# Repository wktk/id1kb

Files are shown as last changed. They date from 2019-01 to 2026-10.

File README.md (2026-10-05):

# id1kb

## parts per 1 PCB

| Name | Value | Comment |
|----|----|----|
| Pro Micro | 1 | |
| SK6812MINI | 8 | Optional |
| Key Switch | 8 | |
| MJ-4PP-9 | 1 | Required only if connect two kbds |
| Diode 1N4148 | 8 | 100V 200mA, Also supports SMD |

## case

3D printable bottom case.

| File | Comment |
|----|----|
| case/id1kb_case.stl | Full floor |
| case/id1kb_case_truss.stl | Truss floor, less material |
| case/id1kb_case.scad | OpenSCAD source, adjust pin size etc. in Customizer |

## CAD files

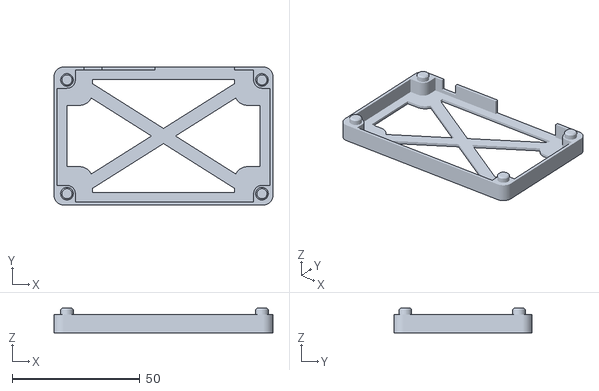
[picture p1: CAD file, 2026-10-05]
case/id1kb_case_truss.stl
85.6 x 54.0 x 9.60

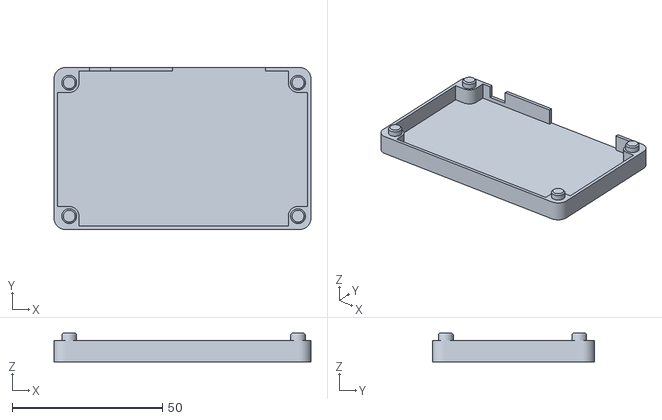
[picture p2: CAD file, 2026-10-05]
case/id1kb_case.stl
85.6 x 54.0 x 9.60

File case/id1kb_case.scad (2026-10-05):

// id1kb bottom tray case
// The tray shares the PCB's outline: its walls run under the PCB edge and the
// PCB rests on them, held by friction on the pins.
// Coordinates follow the top view (switch side up, "Designed by" text on the right),
// which matches KiCad's front view: origin at the PCB's top-left corner
// (USB/TRRS edge), y' grows downward.

/* [View] */
show_pcb = false;

/* [Board fit] */
// Clearance under the PCB for the Pro Micro, TRRS jack and reset switch.
under = 6.0;
pin_d = 4.95;
// How far the pin tip rises above the PCB's top surface.
pin_extra = 0.8;

/* [Openings] */
// The Pro Micro overhangs the top edge by ~2 mm, so the whole module needs room.
promicro_w = 20;
trrs_w = 9;
reset_w = 7;
reset_depth = 4.5;

/* [Case] */
floor_style = "full"; // [full, truss]
floor_t = 1.2;
wall = 1.2;
post_d = 6.5;

/* [Truss floor] */
truss_w = 5;
// Square pad inside each frame corner, room for a rubber foot.
foot_pad = 10;
// Radius of the pad's corner that faces the middle.
foot_r = 5;

/* [Hidden] */
$fn = 64;

pcb_w = 85.6;
pcb_h = 53.98;
pcb_r = 3.81;
pcb_t = 1.6;

holes = [[5.08, 5.08], [81.28, 5.08], [5.08, 49.53], [81.28, 49.53]];
promicro_x = 49.53;
trrs_x = 66.0;
reset_x = 15.28;
switches = [for (x = [11.43, 30.48, 49.53, 68.58], y = [21.59, 40.64]) [x, y]];

function pos(p) = [p[0], pcb_h - p[1]];

z_pcb = floor_t + under;

module outline(off) {
    translate([pcb_r, pcb_r])
        offset(r = pcb_r + off) square([pcb_w - 2 * pcb_r, pcb_h - 2 * pcb_r]);
}

// Measured from the PCB's corner, so it also covers the frame under the pad.
module foot_pad() {
    t = truss_w + foot_pad;
    square([t, t - foot_r]);
    square([t - foot_r, t]);
    translate([t - foot_r, t - foot_r]) circle(r = foot_r);
}

module floor_2d() {
    if (floor_style == "full") outline(0);
    else intersection() {
        outline(0);
        union() {
            difference() { outline(0); outline(-truss_w); }
            for (d = [[[0, 0], [pcb_w, pcb_h]], [[0, pcb_h], [pcb_w, 0]]])
                hull() for (p = d) translate(p) circle(d = truss_w);
            for (mx = [0, 1], my = [0, 1])
                translate([mx * pcb_w, my * pcb_h]) mirror([mx, 0]) mirror([0, my]) foot_pad();
        }
    }
}

module shell() {
    difference() {
        linear_extrude(z_pcb) outline(0);
        translate([0, 0, -1]) linear_extrude(z_pcb + 2) outline(-wall);
    }
    linear_extrude(floor_t) floor_2d();
}

// Starts slightly below its base so it fuses with the post instead of just touching it.
module pin(d) {
    hull() {
        translate([0, 0, -0.1]) cylinder(d = d, h = pcb_t + pin_extra - 0.4);
        cylinder(d = d - 1, h = pcb_t + pin_extra);
    }
}

// Bridged to the two nearest walls so no thin gap is left beside them.
module post_2d(h) {
    c = [h[0] < pcb_w / 2 ? 0 : pcb_w, h[1] < pcb_h / 2 ? 0 : pcb_h];
    intersection() {
        outline(0);
        for (e = [[c[0], h[1]], [h[0], c[1]]])
            hull() for (p = [h, e]) translate(pos(p)) circle(d = post_d);
    }
}

module posts() {
    for (h = holes) {
        linear_extrude(z_pcb) post_2d(h);
        translate(pos(h)) translate([0, 0, z_pcb]) pin(pin_d);
    }
}

module notch(x, w, z0) {
    translate([x - w / 2, pcb_h - wall - 1, z0]) cube([w, wall + 2, z_pcb]);
}

module case() {
    difference() {
        shell();
        // One opening for both: separate notches would leave a fragile ~2 mm strip between them.
        let (l = promicro_x - promicro_w / 2, r = trrs_x + trrs_w / 2)
            notch((l + r) / 2, r - l, floor_t);
        notch(reset_x, reset_w, z_pcb - reset_depth);
    }
    posts();
}

module pcb_ghost() {
    translate([0, 0, z_pcb]) difference() {
        linear_extrude(pcb_t) outline(0);
        for (h = holes) translate(pos(h)) translate([0, 0, -1]) cylinder(d = 4.8, h = pcb_t + 2);
    }
    for (s = switches) translate(pos(s)) translate([-7, -7, z_pcb + pcb_t]) cube([14, 14, 11]);
    translate([promicro_x - 9, pcb_h - 33 + 2, z_pcb - 5]) cube([18, 33, 5]);
    translate([trrs_x - 3, pcb_h - 12, z_pcb - 5]) cube([6, 12, 5]);
    translate([reset_x - 3.75, pcb_h - 8.7, z_pcb - 3.5]) cube([7.5, 7.5, 3.5]);
}

case();
if (show_pcb) %pcb_ghost();

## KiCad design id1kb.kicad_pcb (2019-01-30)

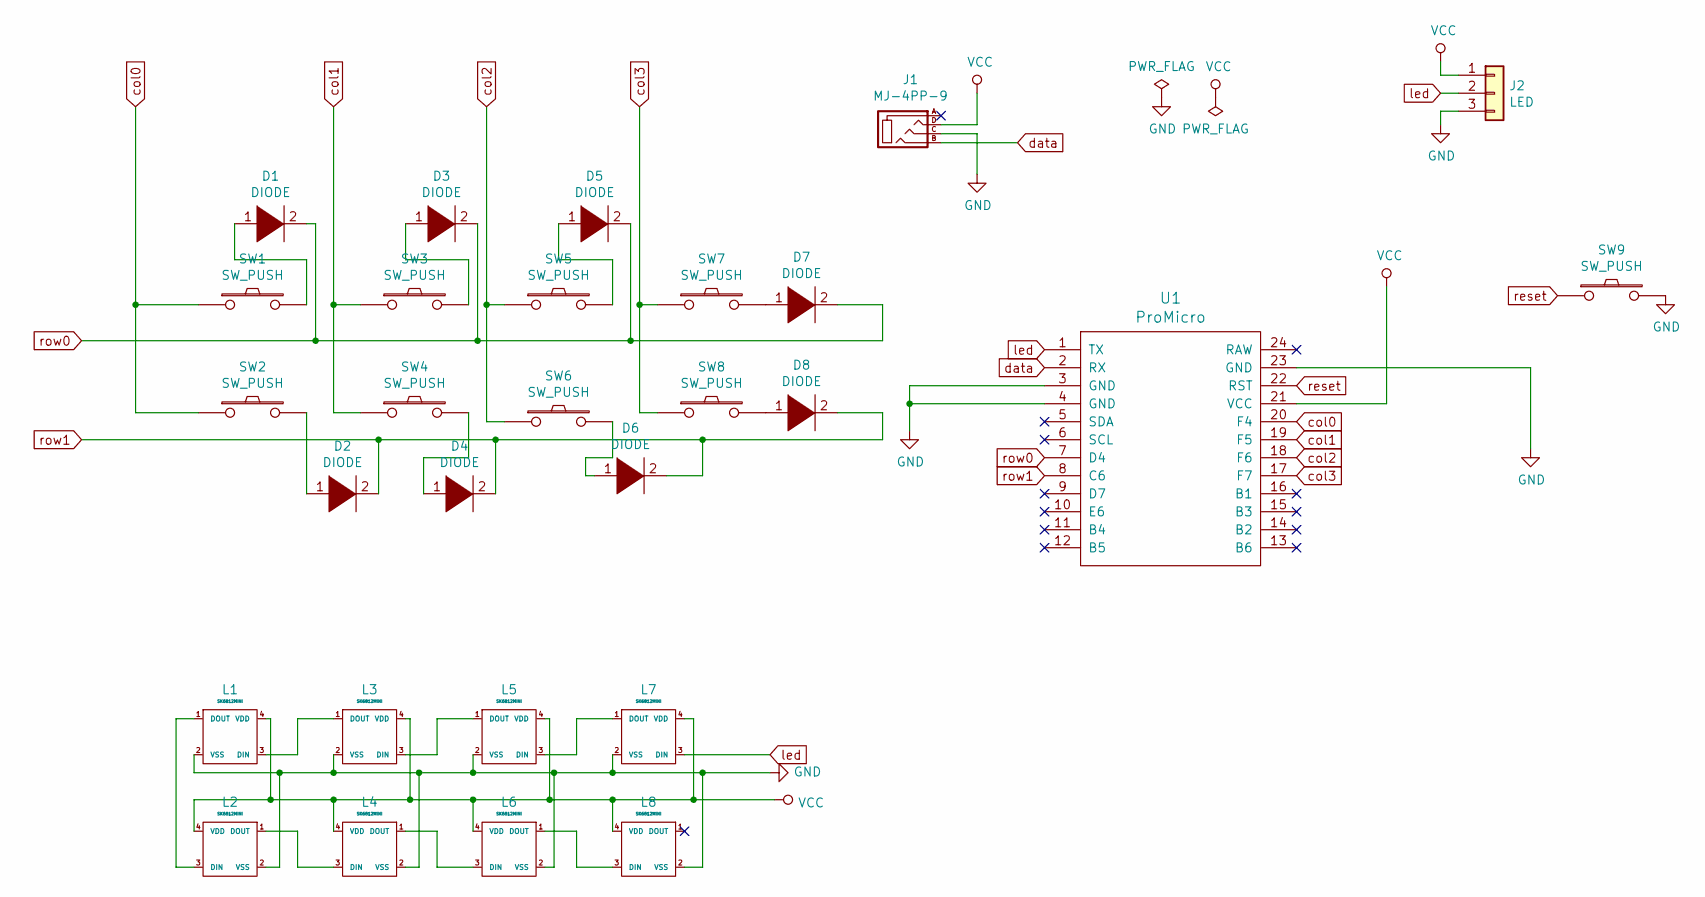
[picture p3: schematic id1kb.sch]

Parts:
D1, D2, D3, D4, D5, D6, D7, D8: DIODE; D3_TH_SMD
J1: MJ-4PP-9
J2: LED; StripLED_rev
L1, L2, L3, L4, L5, L6, L7, L8: SK6812MINI; SK6812MINI_rev
SW1, SW2, SW3, SW4, SW5, SW6, SW7, SW8: SW_PUSH; Hybrid_PCB_100H_Dual_hole
SW9: SW_PUSH; SW_Tactile_SPST_Angled_MJTP1117
U1: ProMicro; ArduinoProMicro-BackSide

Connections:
GND: J1.C, J2.3, L1.2 (VSS), L2.2 (VSS), L3.2 (VSS), L4.2 (VSS), L5.2 (VSS), L6.2 (VSS), L7.2 (VSS), L8.2 (VSS), SW9.2, U1.3 (GND), U1.4 (GND), U1.23 (GND); also elsewhere on the board
unnamed: D1.1 (K), SW1.2
unnamed: D2.1 (K), SW2.2
unnamed: D3.1 (K), SW3.2
unnamed: D4.1 (K), SW4.2
unnamed: D5.1 (K), SW5.2
unnamed: D6.1 (K), SW6.2
unnamed: D7.1 (K), SW7.2
unnamed: D8.1 (K), SW8.2
unnamed: L1.1 (DOUT), L2.3 (DIN)
unnamed: L1.3 (DIN), L3.1 (DOUT)
unnamed: L2.1 (DOUT), L4.3 (DIN)
unnamed: L3.3 (DIN), L5.1 (DOUT)
unnamed: L4.1 (DOUT), L6.3 (DIN)
unnamed: L5.3 (DIN), L7.1 (DOUT)
unnamed: L6.1 (DOUT), L8.3 (DIN)
unnamed 18: U1.5 (SDA); also elsewhere on the board
unnamed 19: U1.6 (SCL); also elsewhere on the board
unnamed 20: U1.9 (D7); also elsewhere on the board
unnamed 21: U1.10 (E6); also elsewhere on the board
unnamed 22: U1.11 (B4); also elsewhere on the board
unnamed 23: U1.12 (B5); also elsewhere on the board
unnamed 24: U1.13 (B6); also elsewhere on the board
unnamed 25: U1.14 (B2); also elsewhere on the board
unnamed 26: U1.15 (B3); also elsewhere on the board
unnamed 27: U1.16 (B1); also elsewhere on the board
unnamed 28: U1.24 (RAW); also elsewhere on the board
VCC: J1.D, J2.1, L1.4 (VDD), L2.4 (VDD), L3.4 (VDD), L4.4 (VDD), L5.4 (VDD), L6.4 (VDD), L7.4 (VDD), L8.4 (VDD), U1.21 (VCC); also elsewhere on the board
col0: SW1.1, SW2.1, U1.20 (F4); also elsewhere on the board
col1: SW3.1, SW4.1, U1.19 (F5); also elsewhere on the board
col2: SW5.1, SW6.1, U1.18 (F6); also elsewhere on the board
col3: SW7.1, SW8.1, U1.17 (F7); also elsewhere on the board
data: J1.B, U1.2 (RX); also elsewhere on the board
led: J2.2, L7.3 (DIN), U1.1 (TX); also elsewhere on the board
reset: SW9.1, U1.22 (RST); also elsewhere on the board
row0: D1.2 (A), D3.2 (A), D5.2 (A), D7.2 (A), U1.7 (D4); also elsewhere on the board
row1: D2.2 (A), D4.2 (A), D6.2 (A), D8.2 (A), U1.8 (C6); also elsewhere on the board

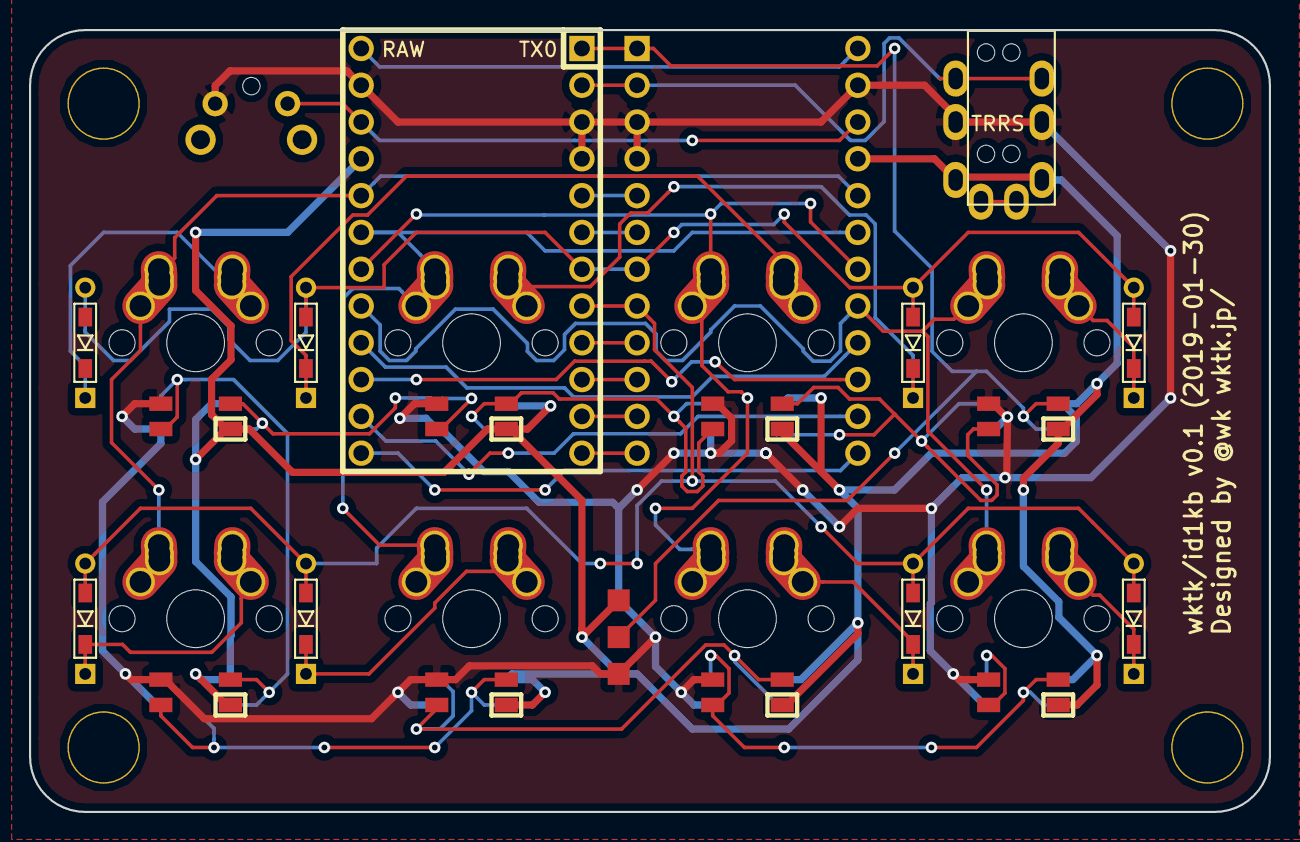
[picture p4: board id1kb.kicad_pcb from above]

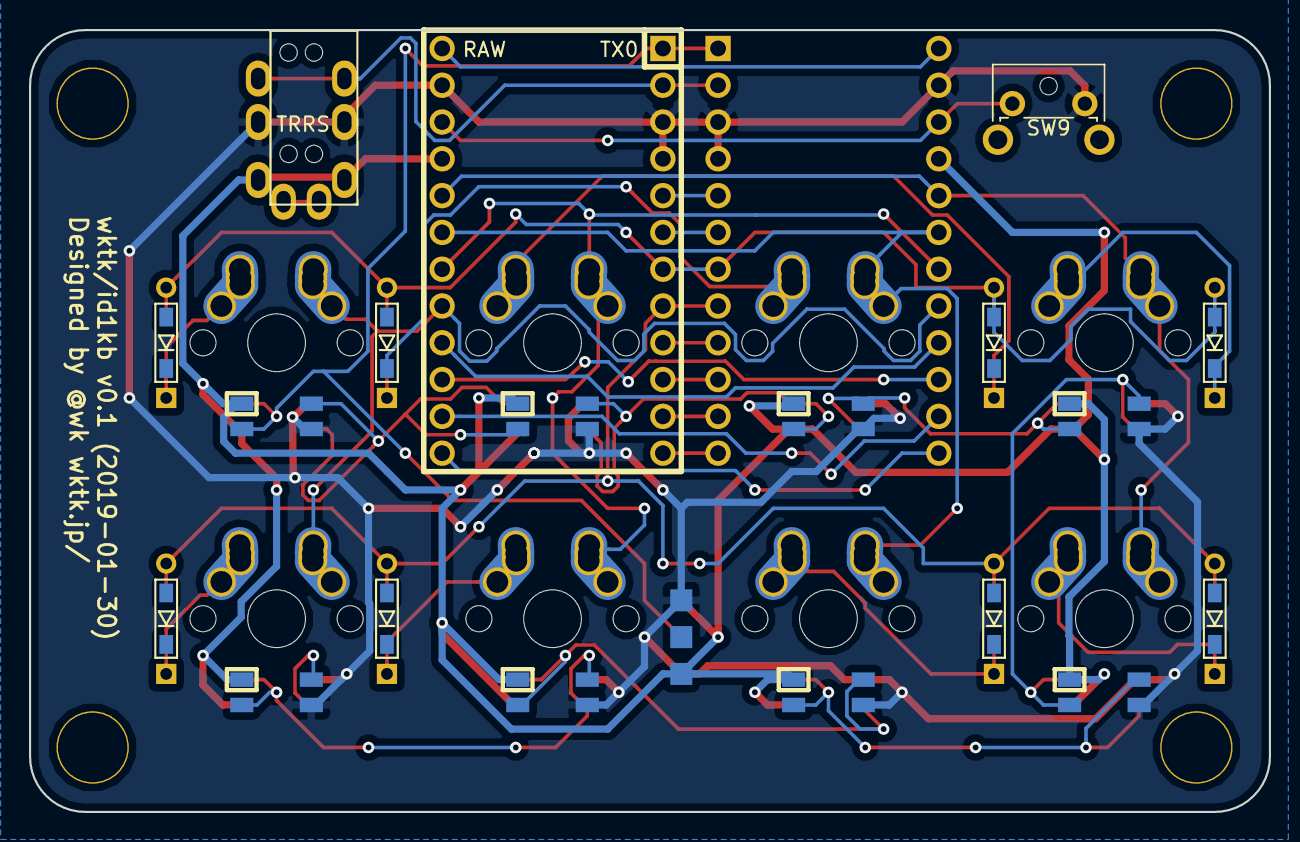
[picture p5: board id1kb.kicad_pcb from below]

Board: 2 copper layers, 85.6 x 54.0 mm, 33 parts (11 on the bottom side), 37 nets.

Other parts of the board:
Ref**: Val**; HOLE
Ref**#2, Ref**#3, Ref**#4: Val**; HOLE
U1#2: ProMicro; ArduinoProMicro-BackSide

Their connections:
GND: U1#2.3, U1#2.4, U1#2.23; also elsewhere on the board
unnamed 18: U1#2.5; also elsewhere on the board
unnamed 19: U1#2.6; also elsewhere on the board
unnamed 20: U1#2.9; also elsewhere on the board
unnamed 21: U1#2.10; also elsewhere on the board
unnamed 22: U1#2.11; also elsewhere on the board
unnamed 23: U1#2.12; also elsewhere on the board
unnamed 24: U1#2.13; also elsewhere on the board
unnamed 25: U1#2.14; also elsewhere on the board
unnamed 26: U1#2.15; also elsewhere on the board
unnamed 27: U1#2.16; also elsewhere on the board
unnamed 28: U1#2.24; also elsewhere on the board
VCC: U1#2.21; also elsewhere on the board
col0: U1#2.20; also elsewhere on the board
col1: U1#2.19; also elsewhere on the board
col2: U1#2.18; also elsewhere on the board
col3: U1#2.17; also elsewhere on the board
data: U1#2.2; also elsewhere on the board
led: U1#2.1; also elsewhere on the board
reset: U1#2.22; also elsewhere on the board
row0: U1#2.7; also elsewhere on the board
row1: U1#2.8; also elsewhere on the board

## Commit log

2019-01-27 配線の手前まで作成
    [mykeyboard.kicad_pcb, mykeyboard.sch]
2019-01-29 Pro micro の配置と回路の配線
    [mykeyboard.kicad_pcb]
2019-01-30 配線をリセット、ダイオードの位置をまとめた
    [mykeyboard.kicad_pcb]
2019-01-30 LED の回路を設定
    [mykeyboard.sch]
2019-01-30 フットプリントを定義
    [mykeyboard.sch]
2019-01-30 回路図の Pro Micro のフットプリントを Keebio の Backside 版に更新、PCB にフットプリントを全て反映
    [mykeyboard.kicad_pcb]
2019-01-30 LED を配置、ダイオードの位置を変更
    [mykeyboard.kicad_pcb, mykeyboard.sch]
2019-01-30 裏面 Pro Mirco が接続されていなかったので修正
    [mykeyboard.kicad_pcb]
2019-01-30 配置の順番がおかしくなっていたのを修正、Pro Micro を配線
    [mykeyboard.kicad_pcb]
2019-01-30 配線を済ませた
    [mykeyboard.kicad_pcb]
2019-01-30 余計なビアを削除
    [mykeyboard.kicad_pcb]
2019-01-30 スペーサの穴を確保
    [mykeyboard.kicad_pcb]
2019-01-30 GND の塗りつぶし
    [mykeyboard.kicad_pcb]
2019-01-30 Add credit
    [mykeyboard.kicad_pcb]
2019-01-30 余裕がありそうなのでクレカサイズに変更、配線位置を一部内側に
    [mykeyboard.kicad_pcb]
2019-01-30 GND を塗りつぶし
    [mykeyboard.kicad_pcb]
2019-01-30 保存して終了
    [mykeyboard.kicad_pcb]
2019-01-30 ガーバーファイルを生成
    [mykeyboard-B.Cu.gbr, mykeyboard-B.Mask.gbr, mykeyboard-B.SilkS.gbr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]
2019-01-30 SW5 の LED が結線できていなかったのを修正
    [mykeyboard.kicad_pcb]
2019-01-30 ガーバーを再生成
    [mykeyboard-B.Cu.gbr, mykeyboard-B.Mask.gbr, mykeyboard-B.SilkS.gbr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]
2019-01-30 塗りつぶしを再実行
    [mykeyboard.kicad_pcb]
2019-01-30 訂正前の ZIP を追加
2019-01-30 ZIP ファイルを更新
2019-01-31 Rename mykeyboard* => id1kb*
    [id1kb-B.Cu.gbr, id1kb-B.Mask.gbr, id1kb-B.SilkS.gbr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]
2019-02-12 Fix cache
    [_saved_id1kb.sch]
2026-10-05 Add 3D-printable bottom tray case
    OpenSCAD model sized to the PCB outline with walls under the PCB edge,
    6 mm of clearance for the Pro Micro, TRRS and reset switch, and pins
    that hold the PCB by friction in the mounting holes.
    [id1kb_case.scad, id1kb_case.stl]
2026-10-05 Drop test-only parts from case model
    Keep only the parameters that may need adjusting for individual boards
    and hide values fixed by the PCB design from the Customizer.
    [id1kb_case.scad]
2026-10-05 Add truss floor variant and slim down the case
    floor_style selects a full floor or a truss floor (outer frame, diagonal
    braces and corner pads for rubber feet). Walls and floor are now 1.2 mm,
    and the posts are bridged to the adjacent walls so no thin gap remains.
    [id1kb_case.scad, id1kb_case.stl, id1kb_case_truss.stl]
2026-10-05 Describe case files in README
